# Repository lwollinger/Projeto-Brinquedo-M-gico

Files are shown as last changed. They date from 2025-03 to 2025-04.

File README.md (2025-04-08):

# Projeto-Brinquedo-Mágico

O projeto **Brinquedo Mágico** é uma iniciativa da professora **Ivani Cristina Voos**, coordenadora do projeto de pesquisa **BrincAcessível e Serviços Assistidos por Animais**, situado no Instituto Federal de Educação, Ciência e Tecnologia de Santa Catarina – Campus Palhoça Bilíngue. O desenvolvimento do acionador de brinquedos foi feito pelo aluno **Lucas Martins Wollinger**, estudante de engenharia eletrônica DAELN no Instituto Federal de Educação, Ciência e Tecnologia de Santa Catarina – Campus Florianópolis.

**O principal objetivo é projetar e desenvolver um acionador de brinquedos para auxiliar crianças com deficiência, permitindo que elas tenham autonomia relacional no ato de brincar, sem a necessidade de ajuda constante de um adulto.**

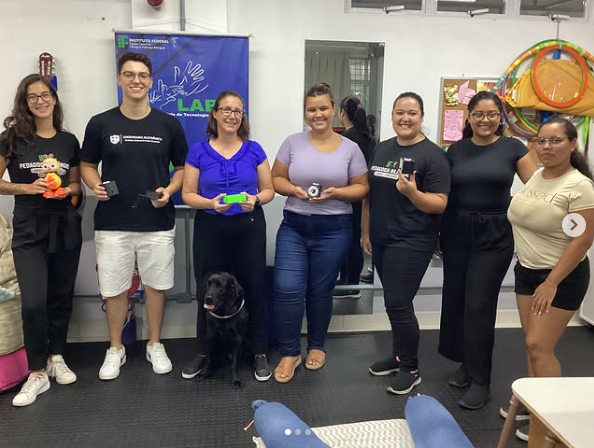
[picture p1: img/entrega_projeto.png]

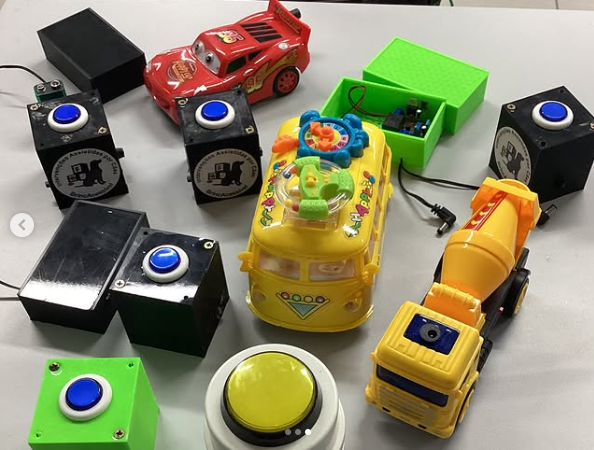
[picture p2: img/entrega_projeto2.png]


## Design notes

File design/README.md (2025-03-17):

# Design:

Durante o desenvolvimento do projeto, optou-se por utilizar um circuito totalmente analógico devido à falta de conhecimento sobre microcontroladores na época, ao domínio da eletrônica analógica por parte do desenvolvedor e à disponibilidade de tempo para a conclusão do projeto. Dessa forma, a escolha se mostrou a mais adequada.

Uma próxima evolução do projeto, será faze-lo com um microcontrolar.

## Principais componentes usados:

* NE 555
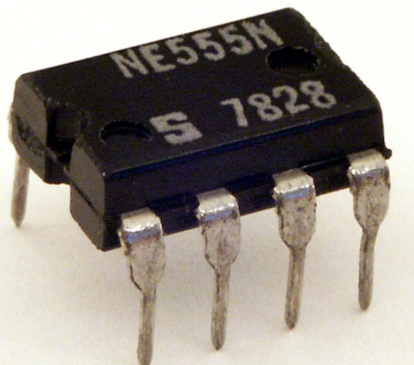
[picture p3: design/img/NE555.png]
    * 
* TSOP4838
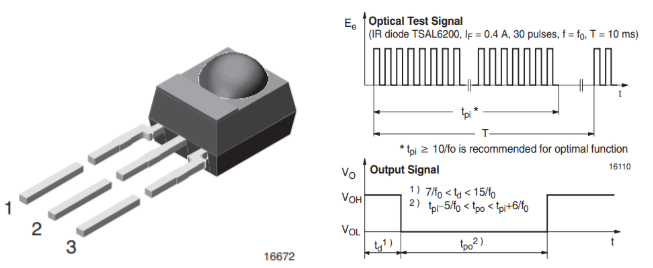
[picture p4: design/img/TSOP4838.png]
    * 
* TSAL6200
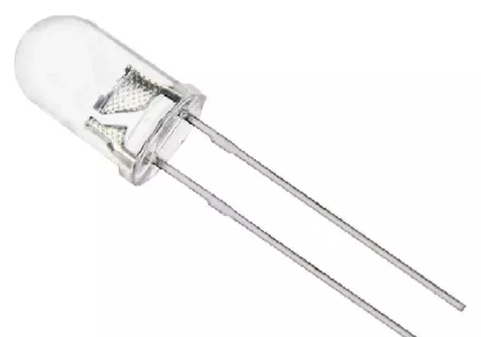
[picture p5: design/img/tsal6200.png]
    * 

## Projeto do Case 

Para o transmissor e receptor foi desenvolvido um case especifico.

* Case do Transmissor
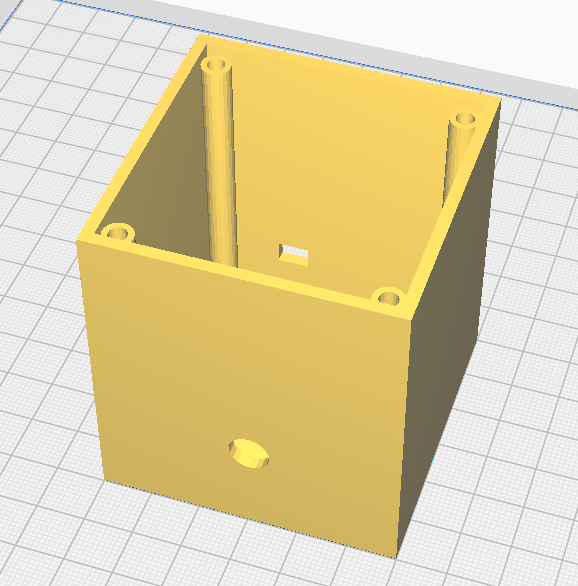
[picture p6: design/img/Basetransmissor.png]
    * 
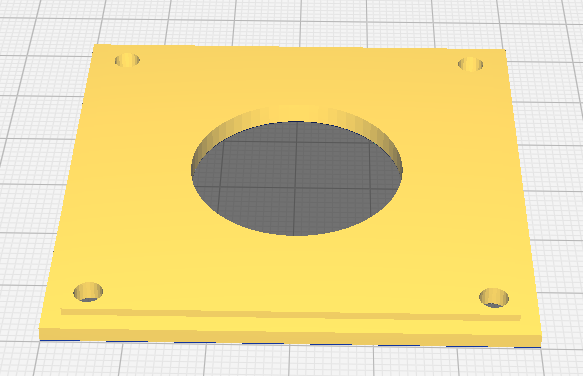
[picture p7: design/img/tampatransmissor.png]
    * 
* Case do Receptor
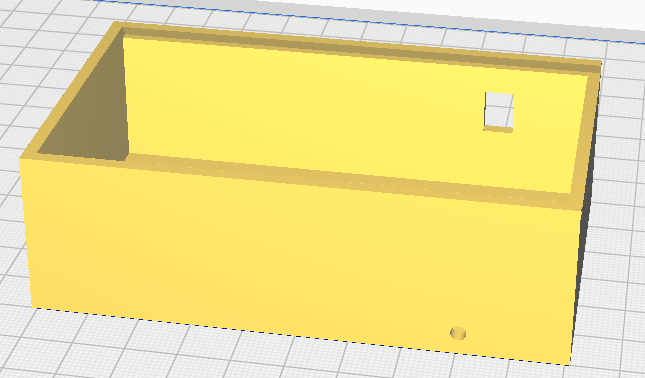
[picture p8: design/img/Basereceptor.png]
    * 
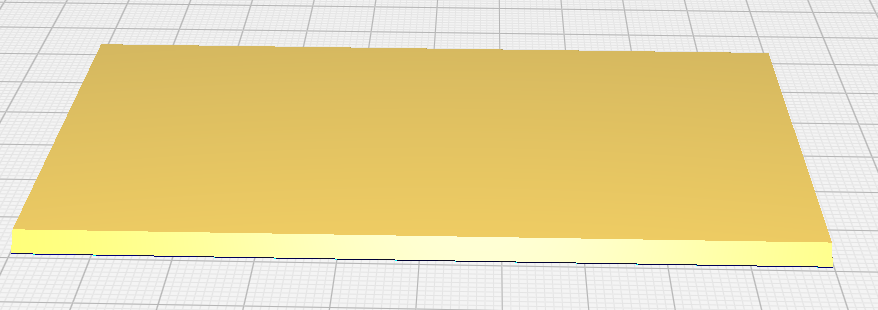
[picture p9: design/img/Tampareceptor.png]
    *

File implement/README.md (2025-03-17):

# Implement

Aqui será mostrada o circuito Brinquedo Mágico em funcionamento.

## Funcionamento

* Formas de Onda Transmissor
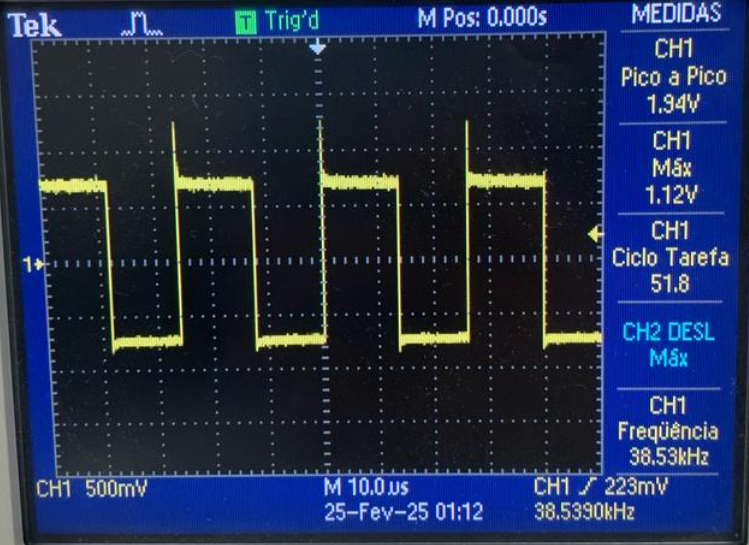
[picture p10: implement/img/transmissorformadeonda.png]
    * 

Pode-se observar que os 50% de duty e os 38kHz foram conquistados com sucesso.

* Circuito Receptor:
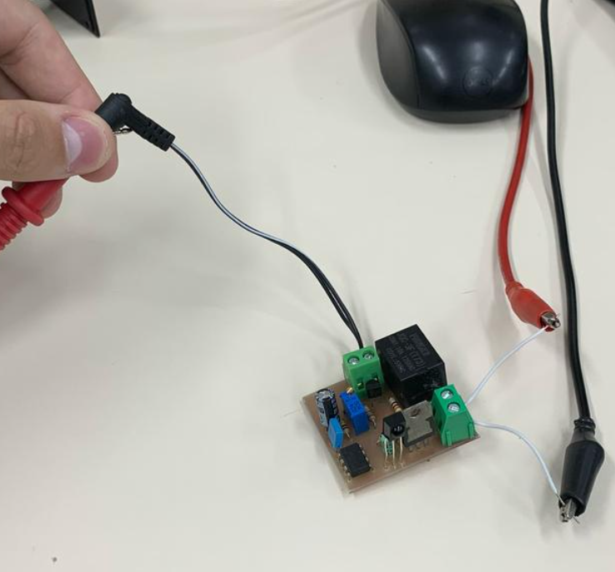
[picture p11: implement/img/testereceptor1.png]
    * 
    * Estado de Modo Comum: (Sem continuidade = Não acionado):
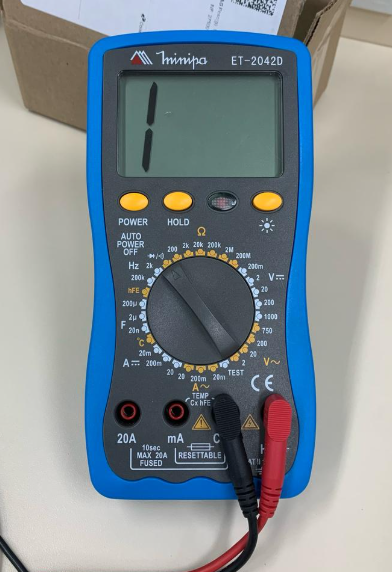
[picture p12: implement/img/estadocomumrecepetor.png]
        * 
    * Estado de Modo Acionado: (Com continuidade = Acionado):
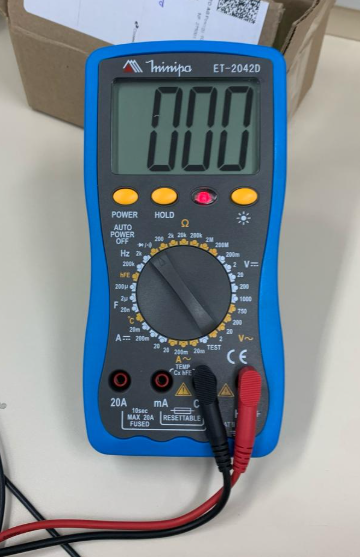
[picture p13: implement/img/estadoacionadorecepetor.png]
    * 

## Conclusão

Portanto, como observado no funcionamento descrito acima, tanto o transmissor quanto o receptor operam conforme o esperado. Após a validação dos testes, será realizada a montagem final e a produção de cinco unidades do **Brinquedo Mágico**.

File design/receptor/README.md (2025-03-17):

# Receptor

## Sensor TSOP4838 38kHz 



A ideia era fazer um acionamento com delay, porém visto na imagem anterior, o circuito receptor quando é detectado 38kHz, ele vai para nível lógico baixo. Isto não seria um problema, porém este estágio de nível lógico baixo ele é muito pequeno (Obs: Mesmo que o transmissor continue acionado, o TSOP4838 volta para nível lógico alto), portanto não seria possível, descarregar um capacitor para ter-se um delay no relé. 

Após muita pesquisa, foi chegado a conclusão que o melhor a ser usado seria um NE555 com modo monoestável, onde ainda seria possível determinar o tempo de acionamento do brinquedo.

## Multivibrador Monoestável

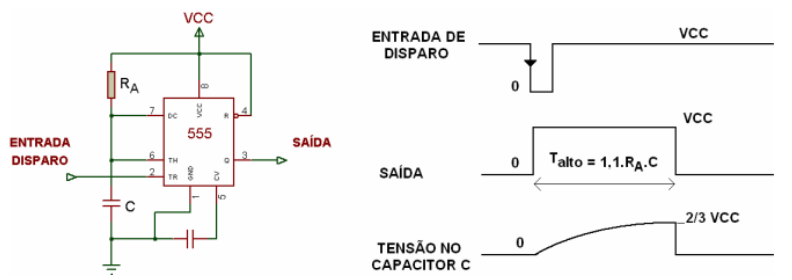
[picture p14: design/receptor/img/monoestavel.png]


A operação monoestável é a responsável pela caracterização do 555 como uma “máquina de temporização”. É justamente essa operação que ativa a saída do 555 por um determinado tempo. Quando o sinal na entrada de disparo apresentar uma borda negativa, o comparador relativo a essa entrada aciona o Flip-Flop do 555 e a saída deste vai a nível alto, permanecendo aí por um período de tempo dado por:

Talto = 1.1 * RA * C

O circuito do temporizador 555 foi configurado no modo monoestável. Quando ocorre uma borda de descida no pino de disparo, o comparador de 1/3 Vcc ativa o Flip-Flop, resultando em uma saída em nível lógico alto.
Nesse estado, o capacitor C começa a se carregar por meio do resistor RA utilizando a tensão de alimentação Vcc. Durante o período de carga, a saída do circuito permanece alta. Assim que a tensão no capacitor atinge 2/3 de Vcc, o segundo comparador é acionado, fazendo com que o Flip-Flop altere seu estado e leve a saída ao nível lógico baixo.
Nesse momento, o transistor de descarga conduz, permitindo que o capacitor C se descarregue rapidamente. Esse ciclo pode ser reiniciado com a aplicação de um novo pulso de disparo.

OBS: Se a entrada de disparo permanecer em nível baixo por um tempo superior ao intervalo Talto, a saída permanecerá em nível alto até que o sinal de disparo volte ao nível lógico alto.

## Simulação

o circuito foi simulado no software proteus que não havia o TSOP4838 como componentes, portanto foi usado uma chave para simular o mesmo.

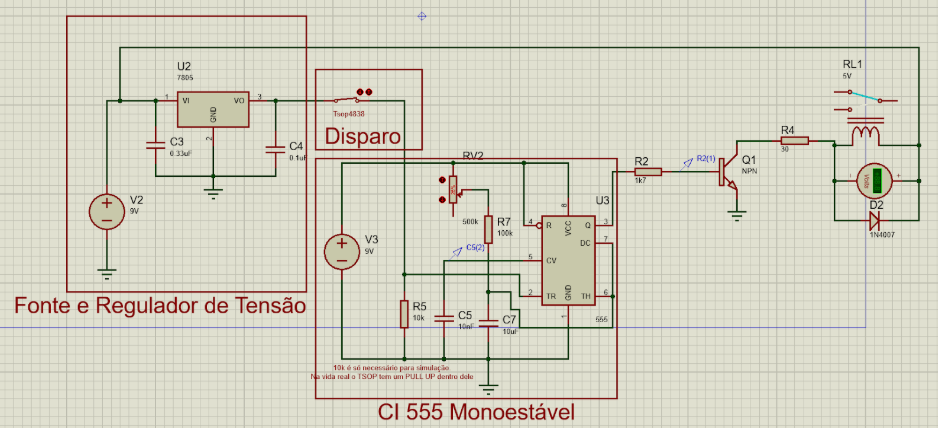
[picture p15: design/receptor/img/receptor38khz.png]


O resistor R5 é apenas uma modelagem para simulação. Na vida real o TSOP tem um resistor de pull-up e por conta deste não se pode adicionar R5.

Quando o circuito é acionado, ou seja, o nível lógico da entrada trigger é baixa, o circuito temporizador inicia a contagem, e portanto seguindo aquela equação vista anteriormente pode-se determinar o tempo que deseja ajustando o potenciômetro.

### Visualização

* Estado comum da chave e do relé.
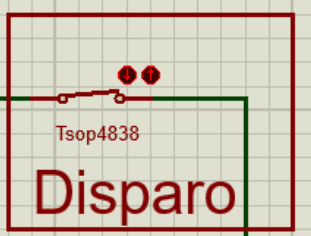
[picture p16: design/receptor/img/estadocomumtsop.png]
    * 
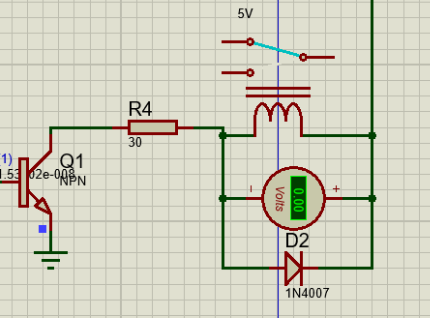
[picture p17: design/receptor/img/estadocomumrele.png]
    * 

* Estado acionado da chave e do relé.
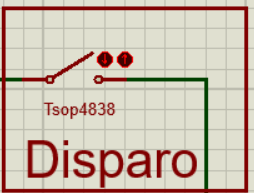
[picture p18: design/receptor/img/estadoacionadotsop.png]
    * 
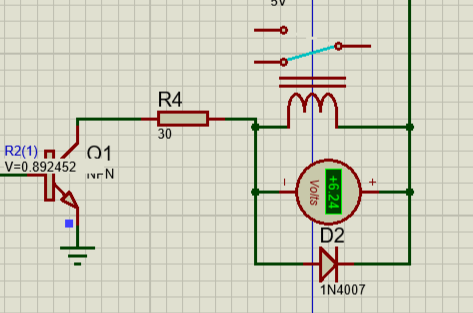
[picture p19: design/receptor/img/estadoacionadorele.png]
    * 

## Montagem 
Toda montagem foi feita no software altium designer.

* Visualização do Layout:
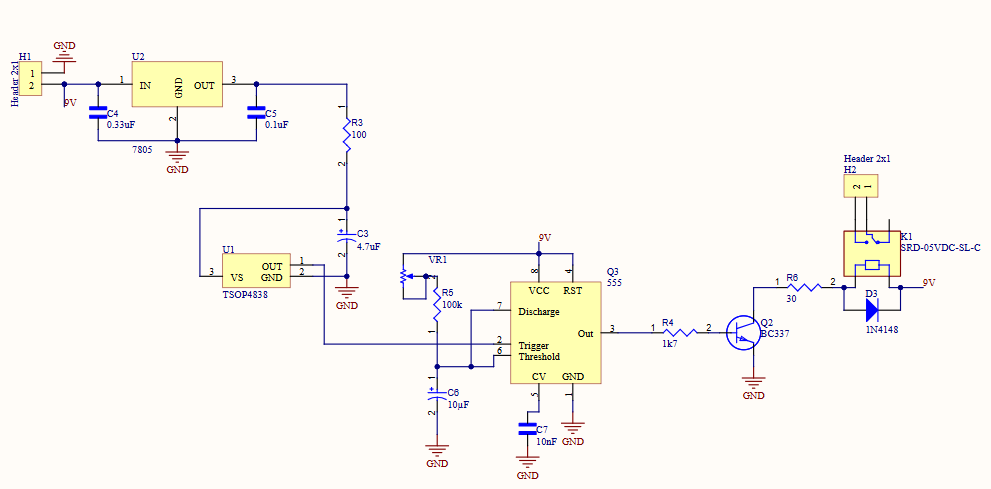
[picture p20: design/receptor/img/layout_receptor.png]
    * 
* Visualização 3D:
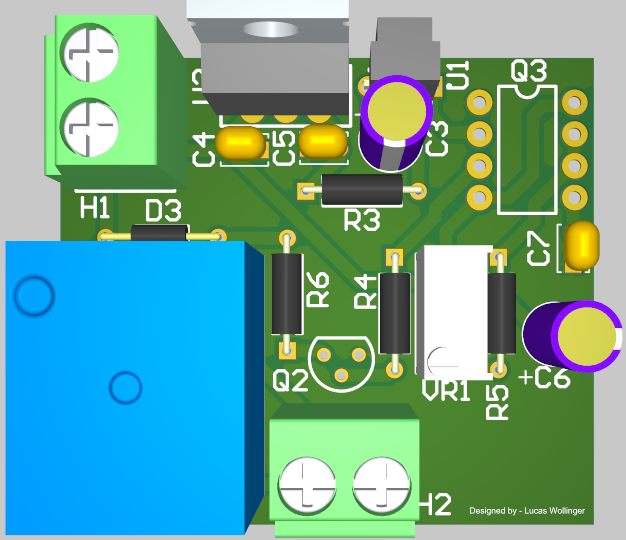
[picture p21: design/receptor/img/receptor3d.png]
    *

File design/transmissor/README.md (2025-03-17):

# Transmissor 

## Led Transmissor IR de Alta Potencia



Foi definido usar este LED em especifico, pois possui uma corrente direta alta e com isso garante ter maior facilidade de acionamento do receptor mesmo se o led não estiver diretamente direcionado para o receptor.

## Multivibrador Astável

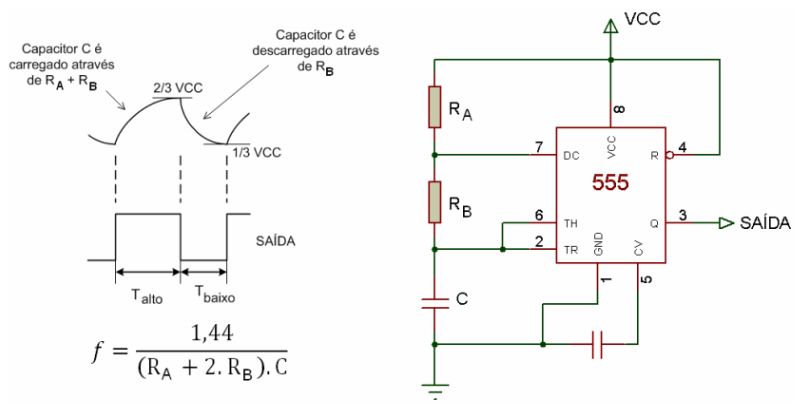
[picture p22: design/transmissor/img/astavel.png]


No modo de operação astável do CI 555, o circuito funciona como um oscilador, gerando uma saída digital com frequência e ciclo de trabalho ajustáveis. O processo ocorre por meio do carregamento e descarregamento contínuo de um capacitor. Inicialmente, o capacitor carrega-se através dos resistores RA e RB até que sua tensão ultrapasse 2/3 Vcc, acionando o comparador interno e disparando o reset do flip-flop, o que faz a saída do pino 3 ir para nível baixo. Nesse momento, um transistor interno é ativado, descarregando o capacitor pelo resistor RB até que sua tensão caia abaixo de 1/3 Vcc. Com isso, o flip-flop é acionado novamente, a saída retorna ao nível alto e o capacitor começa a recarregar. Esse ciclo se repete continuamente, mantendo a tensão do capacitor entre 1/3 Vcc e 2/3 Vcc, resultando em um sinal de onda quadrada na saída.

Neste caso em específico, era necessário 50% de duty cycle e frequência de 38 kHz.

## Simulação

O transmissor foi simulado no software proteus e é um circuito com o CI 555 ligado em modo astável, portanto gerando pulsos quadrados.
Estes pulsos quadrados são de 50% de duty cycle e com 38KHz especificamente.

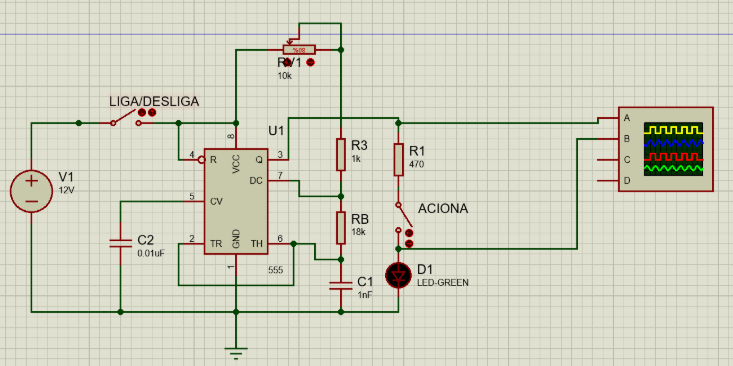
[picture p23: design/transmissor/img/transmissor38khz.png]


### Visualização

* Forma de Onda 38kHz e 50% duty.
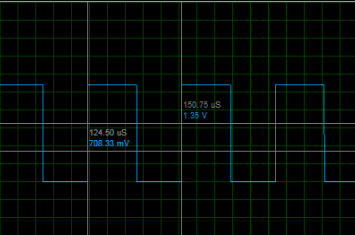
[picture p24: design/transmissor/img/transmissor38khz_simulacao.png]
    * 

f = 1/T = 1 / (150,75us - 124,5us) = 38KHz

## Montagem 
Toda montagem foi feita no software altium designer.

* Visualização do Layout:
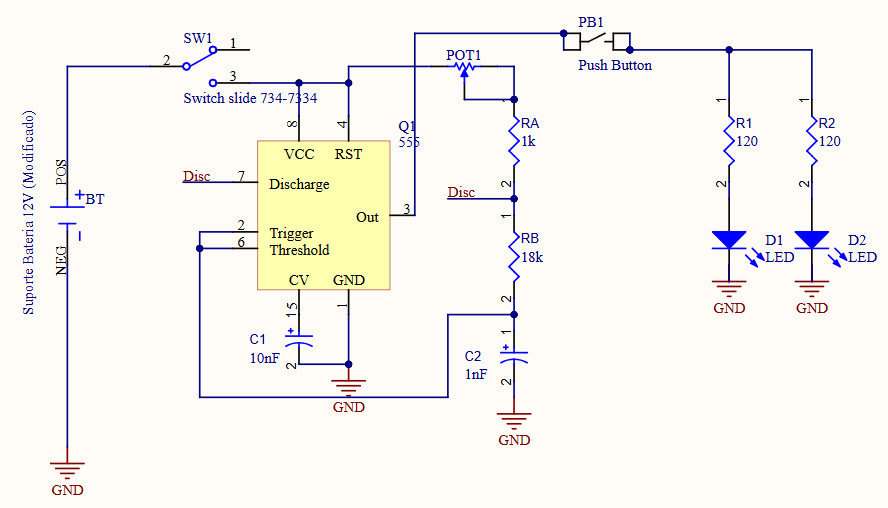
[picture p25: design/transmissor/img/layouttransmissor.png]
    * 
* Visualização 3D:
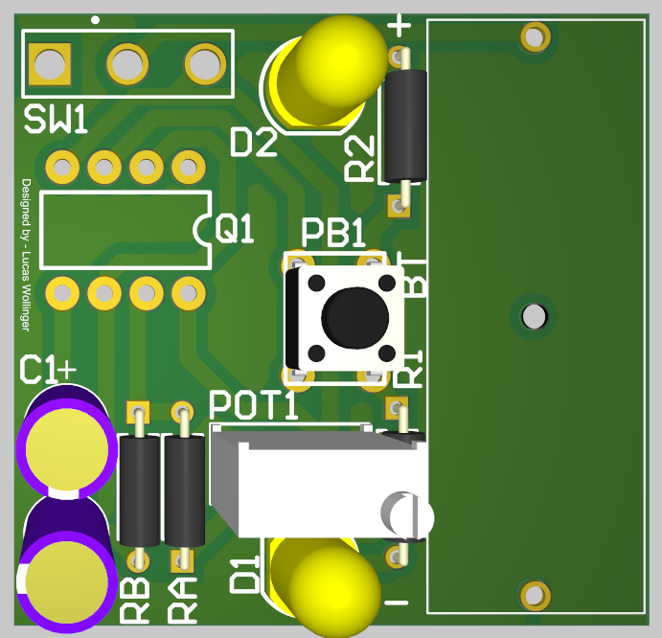
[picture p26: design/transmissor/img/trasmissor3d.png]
    *

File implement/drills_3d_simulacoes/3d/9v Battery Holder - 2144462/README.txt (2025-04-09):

9v Battery Holder by circuito on Thingiverse: https://www.thingiverse.com/thing:2144462

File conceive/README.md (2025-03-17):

# Conceive:

## Objetivos:

Este projeto permite o acionamento remoto de brinquedos por meio de um sistema de transmissão infravermelha (IR). 

Ele conta com um transmissor IR, que pode ser operado à distância por qualquer pessoa, e um receptor IR instalado no brinquedo. Quando o transmissor é ativado, o receptor recebe o sinal e aciona o brinquedo por um tempo determinado, proporcionando uma experiência interativa e acessível.

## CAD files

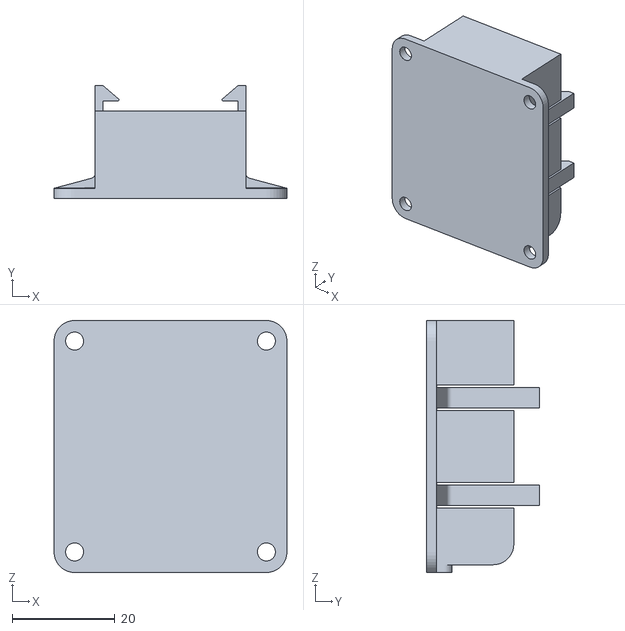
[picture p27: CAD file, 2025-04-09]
implement/drills_3d_simulacoes/3d/9v Battery Holder - 2144462/files/9vcase.STL
45.3 x 22.0 x 49.0

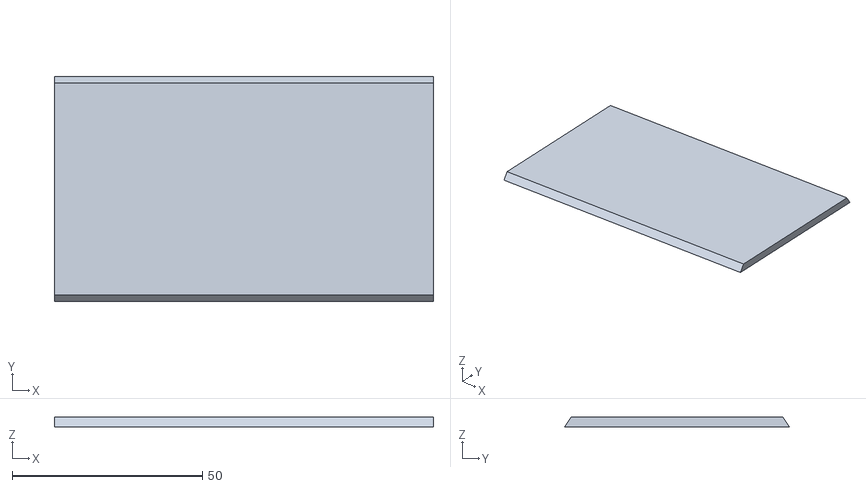
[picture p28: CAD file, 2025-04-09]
implement/drills_3d_simulacoes/3d/Receptor/Tampa_receptor.stl
99.5 x 59.0 x 2.50

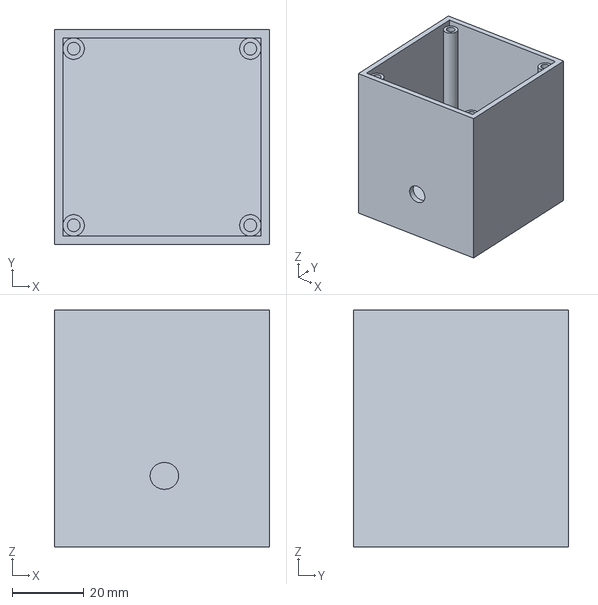
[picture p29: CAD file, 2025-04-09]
implement/drills_3d_simulacoes/3d/Transmissor/CE3PRO_Transmissor_base - Push Button.3mf
60.0 x 60.0 x 66.0 mm

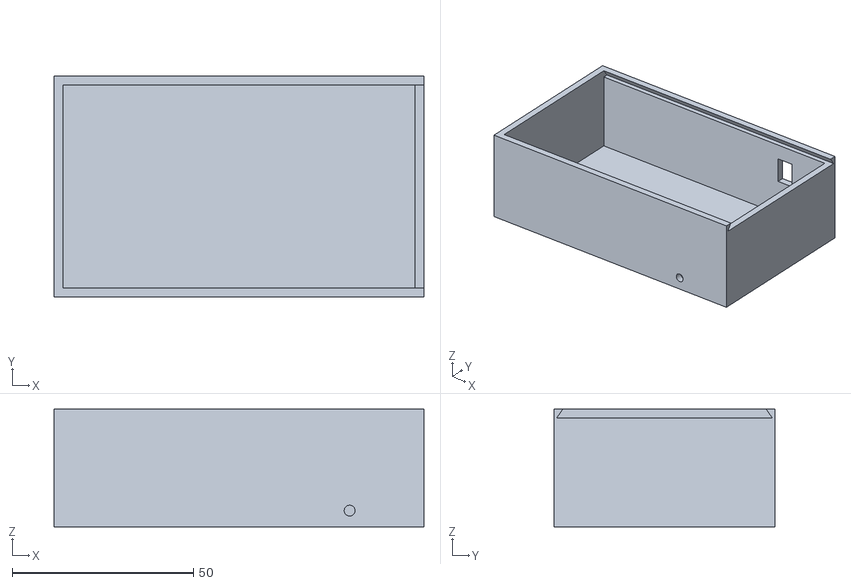
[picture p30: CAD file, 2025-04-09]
implement/drills_3d_simulacoes/3d/Receptor/Caixinha_receptor.stl
102.0 x 61.0 x 32.5

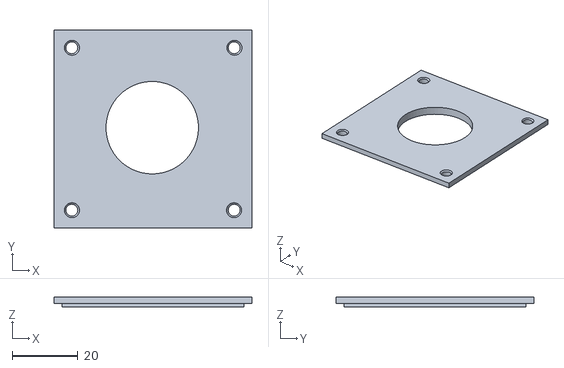
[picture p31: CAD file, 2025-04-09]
implement/drills_3d_simulacoes/3d/Transmissor/Tampa_Transmissor - Push Button.stl
60.0 x 60.0 x 2.99

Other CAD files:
implement/drills_3d_simulacoes/3d/Transmissor/Caxinha_Transmissor - Push Button.stl

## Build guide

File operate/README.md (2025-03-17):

# Operate 

Aqui será mostrado os resultados finais de montagem.

## Montagem final

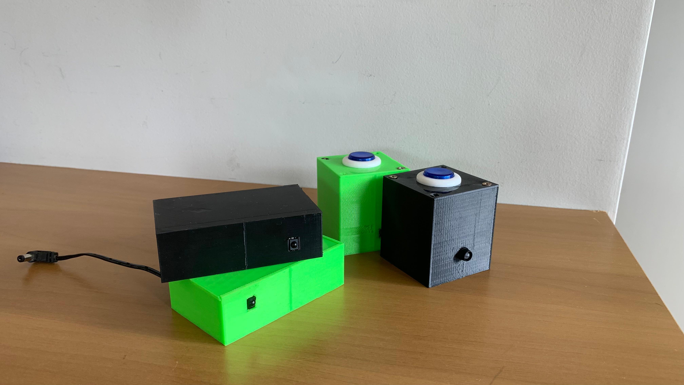
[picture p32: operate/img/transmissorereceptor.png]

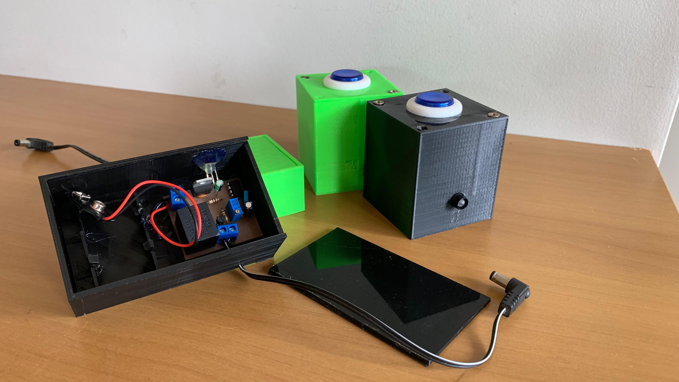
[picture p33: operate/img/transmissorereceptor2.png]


## Referências

Foi necessário um estudo sobre multivibradores e sobre o CI555 para a resolução deste projeto.

**Materiais de apoio:** O TEMPORIZADOR 555 - Charles Borges de Lima / Material Multivibradores - Prof. Clóvis Antônio Petry.

## Agradecimentos

Expresso minha gratidão, em especial, aos professores **Joabel Moia** e **Renan Augusto Starke**, cujo apoio foi fundamental ao longo do desenvolvimento deste projeto. Seus conhecimentos, disposição para esclarecer dúvidas e a disponibilização dos recursos necessários foram essenciais para a concretização deste equipamento.
